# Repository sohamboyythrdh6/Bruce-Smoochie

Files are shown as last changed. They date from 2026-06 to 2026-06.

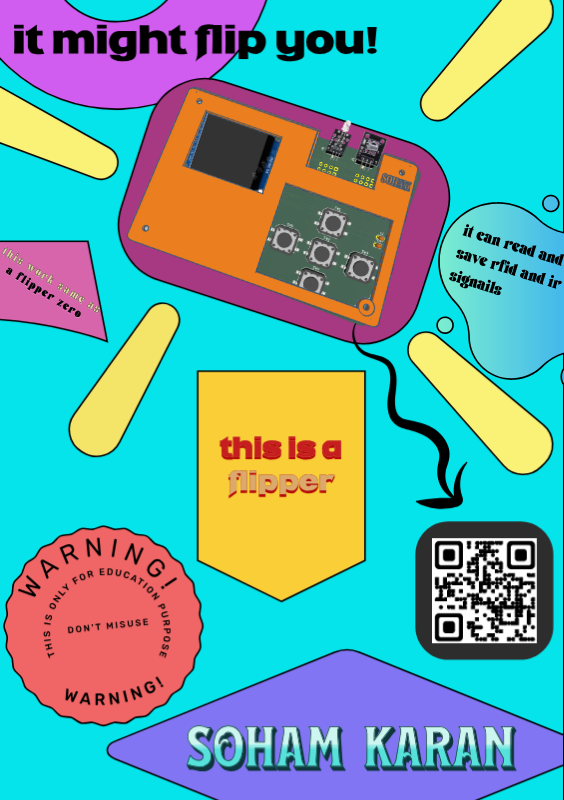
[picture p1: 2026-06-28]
zine.png

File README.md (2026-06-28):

# Bruce-Smoochie
zine

hey my name is soham karan and I am from India. i made a simmiler thing like flipper zero which can read rf tags and save it or use it later it also work same witr ir .And it just work as like flipper zero but it cheapper than flipper and you can also able to made by cheaking this repo .I made this project using esp s3 and some other components .ANd this project is powerd by a lipo battery which is charged by tp4506 charging module.
And to program the board you dont need any code insted you need a flash software which is given in my repo called firmware
and also insted of making a 3d printed case i just use the pcb to create a compact case. You just need to connect the two pcbs using Standoff Spacer Pillars.

                                             !warning! 

this project is just for education and learning purpose so please dont misuse this project.
   !!Bruce is a tool for cyber offensive and red team operations, distributed under the terms of the Affero General Public License (AGPL). It is intended for legal and authorized security testing purposes only. Use of this software for any malicious or unauthorized activities is strictly prohibited. By downloading, installing, or using Bruce, you agree to comply with all applicable laws and regulations. This software is provided free of charge, and we do not accept payments for copies or modifications. The developers of Bruce assume no liability for any misuse of the software. Use at your own risk.!!

  



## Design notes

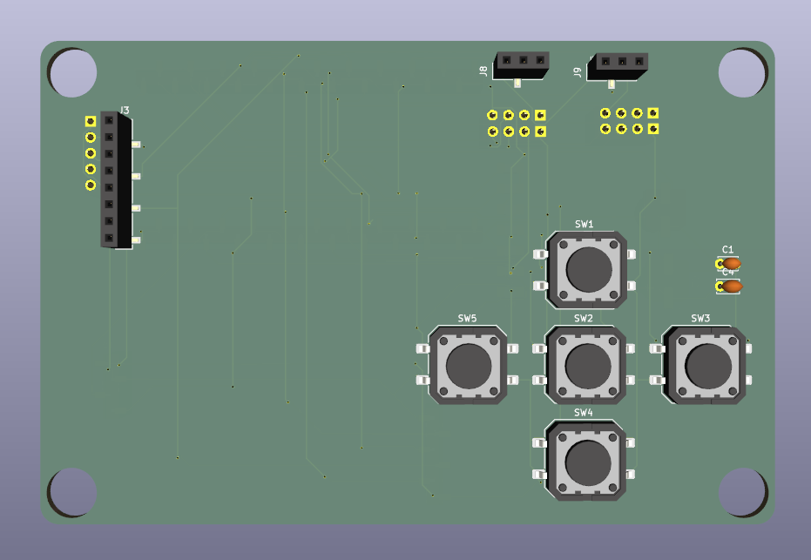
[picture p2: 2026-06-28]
Assets/Screenshot 2026-06-28 220822.png

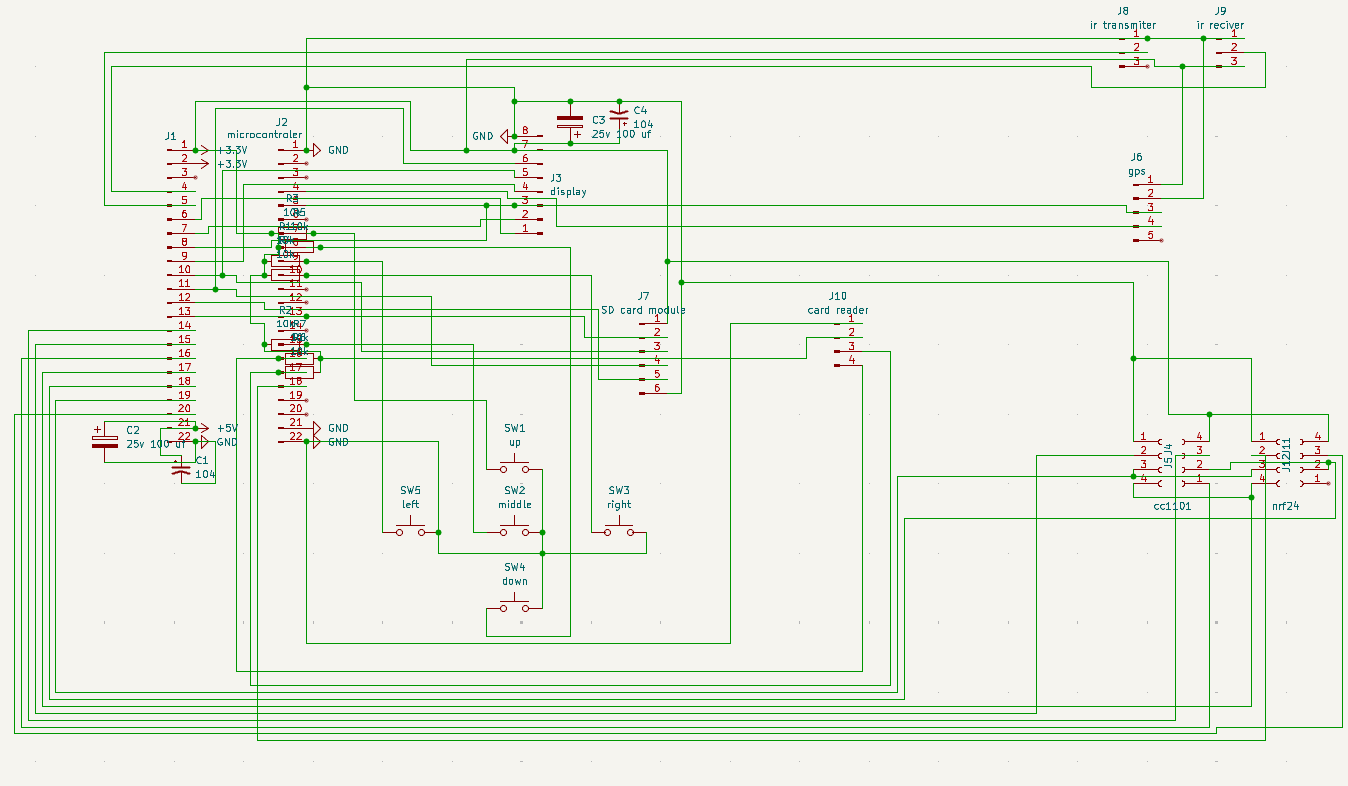
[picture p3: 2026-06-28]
Assets/Screenshot 2026-05-24 214158.png

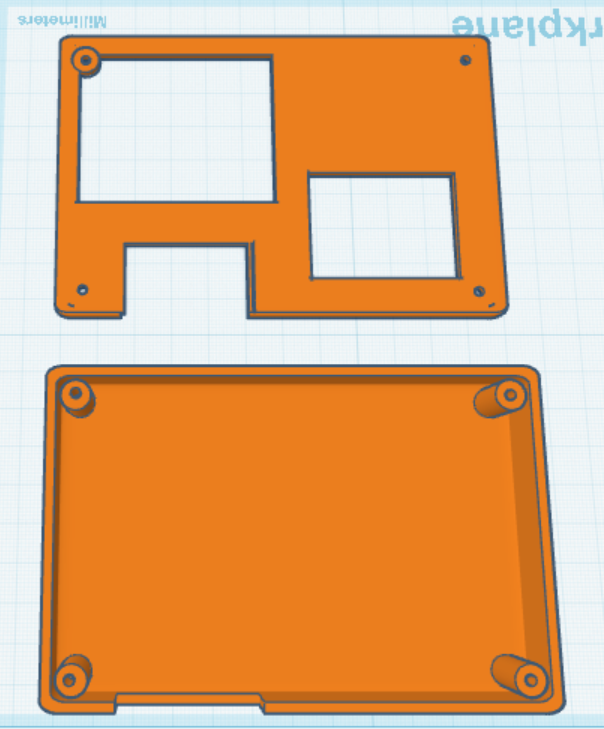
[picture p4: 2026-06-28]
Assets/Screenshot 2026-06-28 214658.png

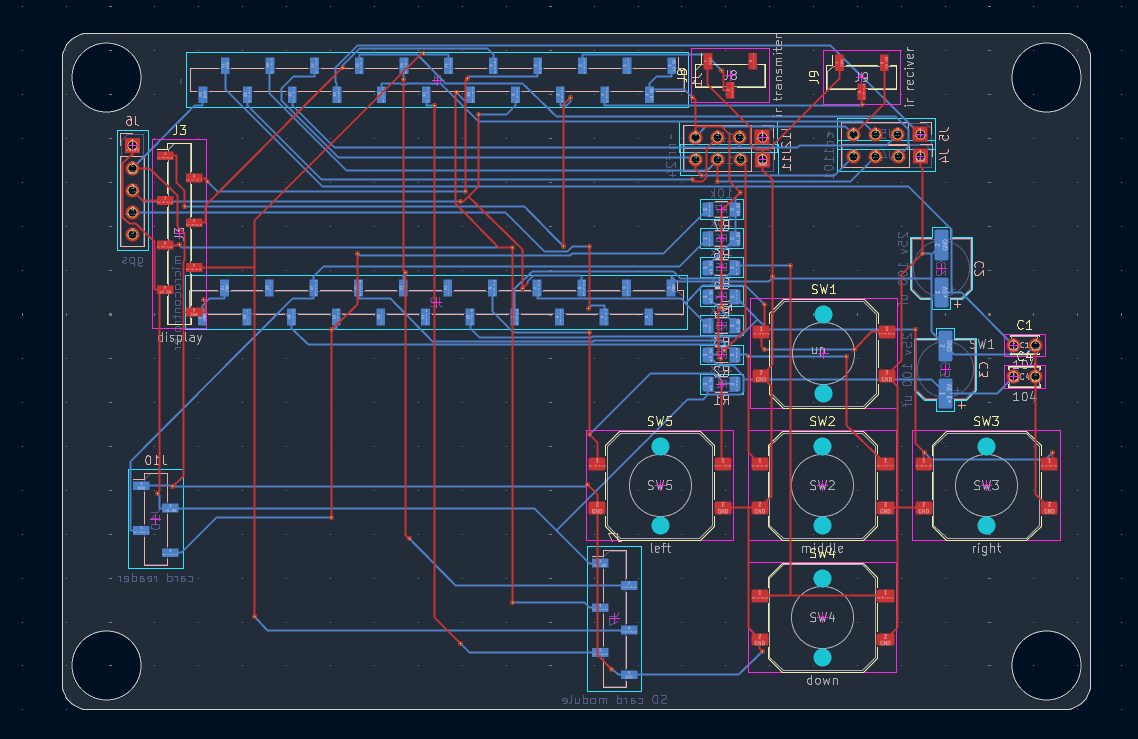
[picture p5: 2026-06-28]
Assets/Screenshot 2026-06-28 220758.png

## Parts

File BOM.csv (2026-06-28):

item | quantity | link | price(Dollar) | description
ESP32-S3 N16R8 | 1 | https://makerbazar.in/products/esp32-s3-wroom-1-development-board-copy?variant=48942521352432 | 10.44 | main controler of this project
1.3inch led tft display | 1 | https://robu.in/product/st7789-driver-spi-interface-display-module/ | 3.76 | for visual settings
Micro SD Card Reader Module | 1 | https://robu.in/product/mini-micro-sd-card-reader-module/ | 0.25 | for read save codes from sd card
8gb micro sd card | 1 | bought from local stors |  | for save codes
NEO GPS Module | 1 | https://makerbazar.in/products/neo-gps-module-neo-m8n-neo-7m-neo-6m?variant=48251052622064 | 2.91 | for trace live location
CC1101 RF Module | 1 | https://quartzcomponents.com/products/cc1101-sma-antenna-wireless-transceiver-module?variant=45714339725546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 | 3.54 | for read rf signals
NRF24L01 Module | 1 | https://makerbazar.in/products/2-4ghz-nrf24l01-pa-lna-sma-wireless-transceiver-antenna?variant=44824810324208 | 1.51 | for generate rf signals
PN532 NFC Module | 1 | https://robu.in/product/pn532-nfc-rfid-read-write-module-v3-kit/ | 2.97 | for read rfid cards
IR Receiver module | 1 | https://robu.in/product/infrared-receiver-module-arduino/ | 0.23 | for catch ir signals
IR Transmitter Sensor Module | 1 | https://robu.in/product/digital-38khz-infrared-transmitter-module/ | 0.41 | for transmit saved ir signails
4000mah lipo battery | 1 | https://robu.in/product/nova-105080-4000mah-3-7v-micro-lipo-battery-pack/ | 6.51 | for power the flipper
TP4056 Li-ion 18650 3.7V 4.2V Battery Charger Board DC-DC Step Up Boost Module | 1 | https://makerbazar.in/products/3-5v-to-5v-9v-lithium-battery-charge-discharge-adjustable-module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 | 0.51 | for charge the battery and stable the voltage
2.54mm 1x40 Pin Female Single Row SMT Header Strip | 2 | https://robu.in/product/2-54mm-1x40-pin-female-single-row-smt-header-strip-pack-of-5/ | 1.25 | for connect sensore and microcontrolers
2.54mm Pin male Single Row SMT Header | 2 | https://robu.in/product/1-month-warranty-628/ | 1 | for connect components
female pin header | 1 | https://robu.in/product/2-54mm-1x40-pin-female-single-row-header-strip-pack-of-10/ | 0.12 | for connect components
104 ceramic disk capasitor | 2 | https://makerbazar.in/products/ceramic-capacitor?variant=45523163185392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 | 0.20 | for insulating the circuit
button | 5 | https://robu.in/product/tact-switch-tk-012d-4pins-12x12-smd/ | 0.31 | for control the flipper
M4 X 20mm Male to Female Brass Hex Threaded Pillar Standoff Spacer | 4 | https://robu.in/product/m4-x-20mm-male-to-female-brass-hex-threaded-pillar-standoff-spacer-6-pcs/ | 1.66 | for connect pcb boards
4mm Stainless Steel Allen Socket Head Nut-Bolt | 4 | https://makerbazar.in/products/stainless-steel-allen-head-nut-bolt-washer-set?variant=44137335947504 | 0.68 | for connect pcbs
100 uf 25v smd capasitor | 2 | https://robu.in/product/uul1e101mnl1gs-nichicon-100uf-25v-116ma120hz-%c2%b120-smdd8xl10mm-aluminum-electrolytic-capacitors-smd-rohs/ | 1.11 | for capasiting
10k smd resistor | 7 | https://robu.in/product/yageo-10k-ohm-1-4w-1206-surface-mount-chip-resistor-pack-of-50/ | 0.048 | for limiting the current
custom pcb | 1 | https://cart.jlcpcb.com/shopcart/cart/ | 8 | for mount and connect all components
3d printed case | 1 | https://cart.jlcpcb.com/shopcart/cart/ | 4.84 | cover the circuit
deliveri charges | 4 | JLCPCB.ROBU.MAKERBAZAR.QUARTZ | 18
total |  |  | 71

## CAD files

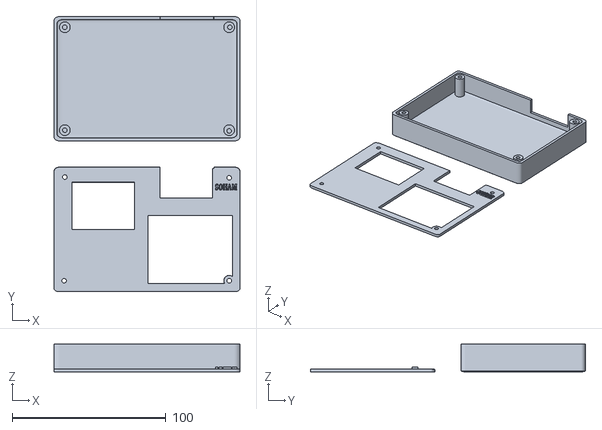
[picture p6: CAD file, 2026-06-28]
CAD/case.stl
121.0 x 179.0 x 18.0

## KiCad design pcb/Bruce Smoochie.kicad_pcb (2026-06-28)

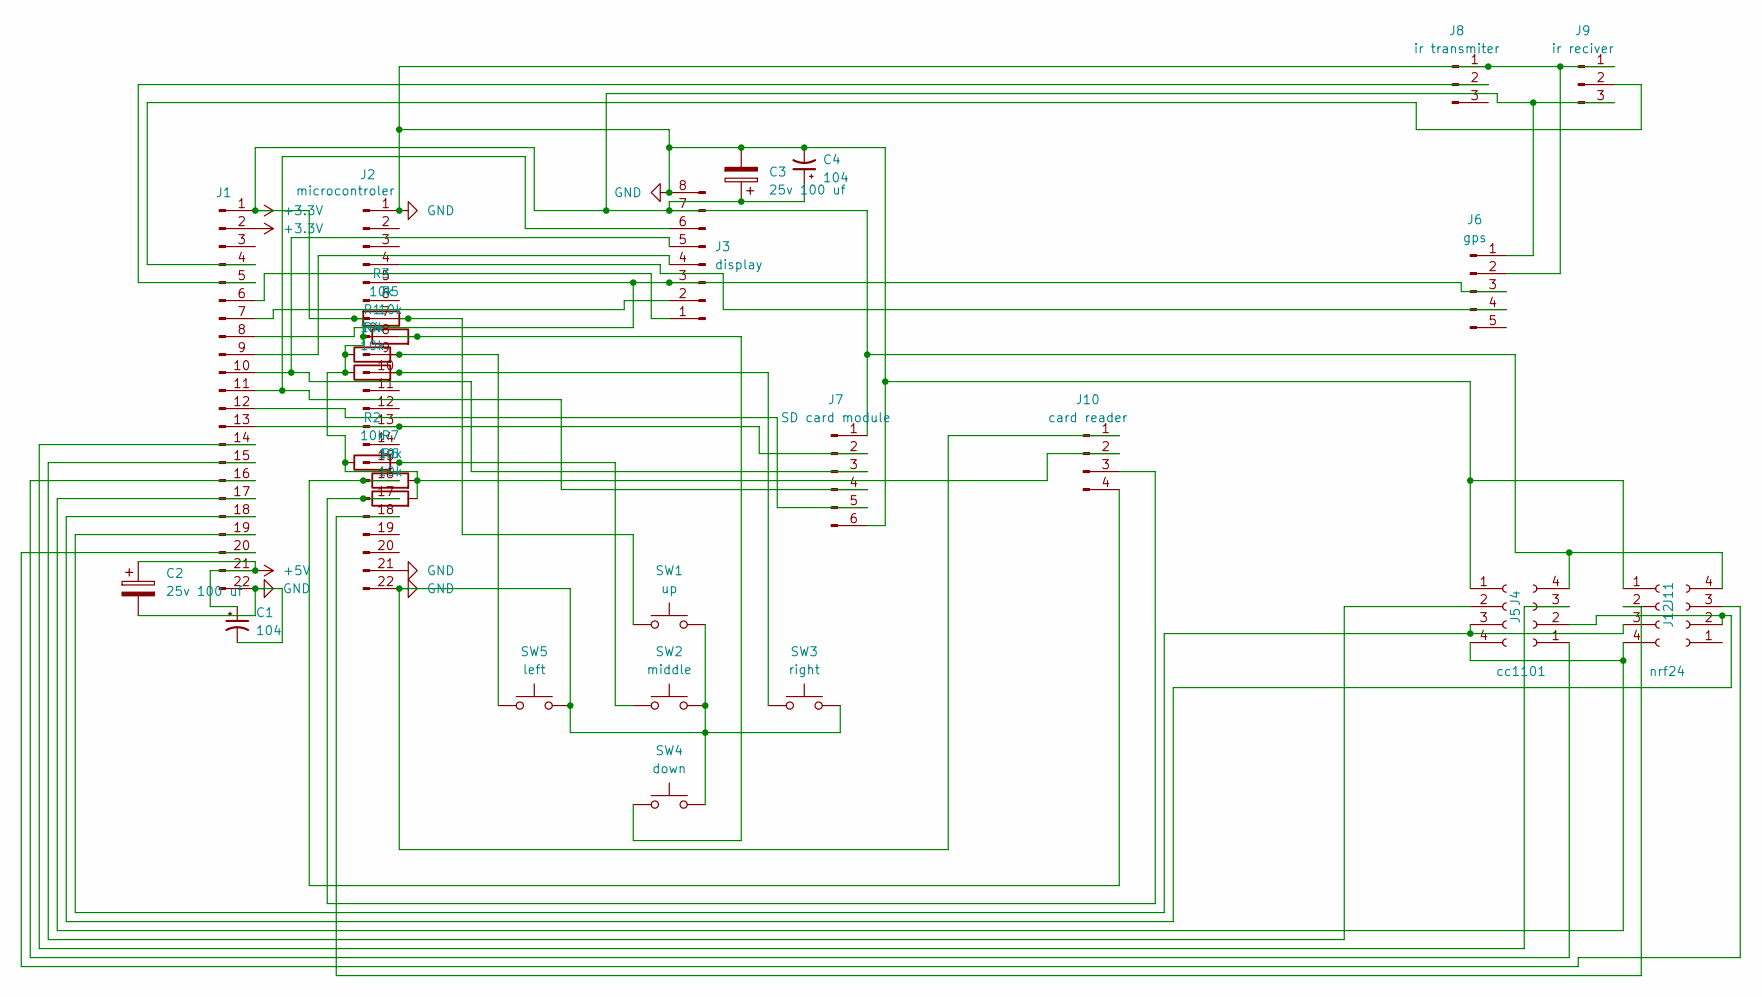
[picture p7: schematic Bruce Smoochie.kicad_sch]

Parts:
C1: 104; C_Disc_D3.0mm_W2.0mm_P2.50mm
C2, C3: 25v 100 uf; CP_Elec_6.3x7.7
C4: 104; C_Disc_D3.4mm_W2.1mm_P2.50mm
J1: PinSocket_1x22_P2.54mm_Vertical_SMD_Pin1Right
J2: microcontroler; PinSocket_1x22_P2.54mm_Vertical_SMD_Pin1Right
J3: display; PinSocket_1x08_P2.54mm_Vertical_SMD_Pin1Left
J4: cc1101; PinSocket_1x04_P2.54mm_Vertical
J5, J12: PinSocket_1x04_P2.54mm_Vertical
J6: gps; PinSocket_1x05_P2.54mm_Vertical
J7: SD card module; PinSocket_1x06_P2.54mm_Vertical_SMD_Pin1Right
J8: ir transmiter; PinSocket_1x03_P2.54mm_Vertical_SMD_Pin1Right
J9: ir reciver; PinSocket_1x03_P2.54mm_Vertical_SMD_Pin1Right
J10: card reader; PinSocket_1x04_P2.54mm_Vertical_SMD_Pin1Right
J11: nrf24; PinSocket_1x04_P2.54mm_Vertical
R1, R2, R3, R4, R5, R6, R7: 10k; R_1206_3216Metric_Pad1.30x1.75mm_HandSolder
SW1: up; SW_Push_1P1T_NO_CK_PTS125Sx43PSMTR
SW2: middle; SW_Push_1P1T_NO_CK_PTS125Sx43PSMTR
SW3: right; SW_Push_1P1T_NO_CK_PTS125Sx43PSMTR
SW4: down; SW_Push_1P1T_NO_CK_PTS125Sx43PSMTR
SW5: left; SW_Push_1P1T_NO_CK_PTS125Sx43PSMTR

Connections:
+3.3V: C3.1, C4.1, J1.1, J1.2, J3.7, J5.4, J6.1, J7.1, J9.3, J10.2, J12.4, R1.1, R2.1, R3.2, R4.1, R5.1, R6.2, R7.2
+5V: C1.1, C2.1, J1.21
GND: C1.2, C2.2, C3.2, C4.2, J1.22, J2.1, J2.21, J2.22, J3.8, J4.1, J6.2, J7.6, J8.1, J9.1, J10.1, J11.1, SW1.2, SW2.2, SW3.2, SW4.2, SW5.2
unnamed: J1.4, J9.2
unnamed: J1.5, J8.2
unnamed: J1.6, J3.1
unnamed: J1.7, J3.2
unnamed: J1.8, J2.5, J3.3, J6.3
unnamed: J1.9, J3.4
unnamed: J1.10, J3.5, J7.3
unnamed: J1.11, J3.6, J7.4
unnamed: J1.12, J7.5
unnamed: J1.13, J2.13, J7.2
unnamed: J1.14, J5.3
unnamed: J1.15, J4.2
unnamed: J1.16, J5.1
unnamed: J1.17, J4.4, J11.4
unnamed: J1.18, J5.2, J12.2
unnamed: J1.19, J4.3, J11.3
unnamed: J1.20, J12.3
unnamed: J2.4, J6.4
unnamed: J2.7, R3.1, SW1.1
unnamed: J2.8, R5.2, SW4.1
unnamed: J2.9, R1.2, SW5.1
unnamed: J2.10, R4.2, SW3.1
unnamed: J2.15, R2.2, SW2.1
unnamed: J2.17, J10.3, R6.1
unnamed: J2.16, J10.4, R7.1
unnamed: J2.18, J11.2

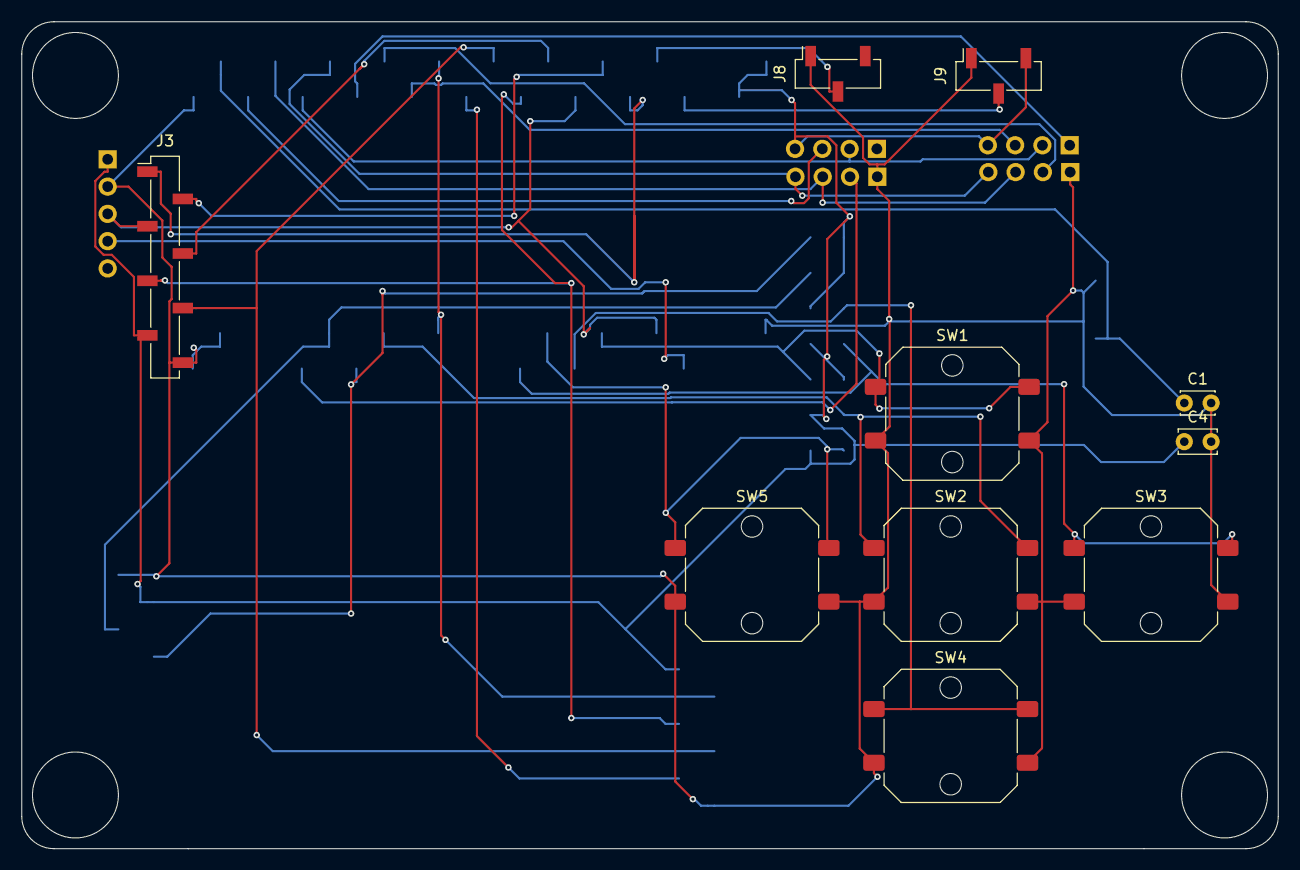
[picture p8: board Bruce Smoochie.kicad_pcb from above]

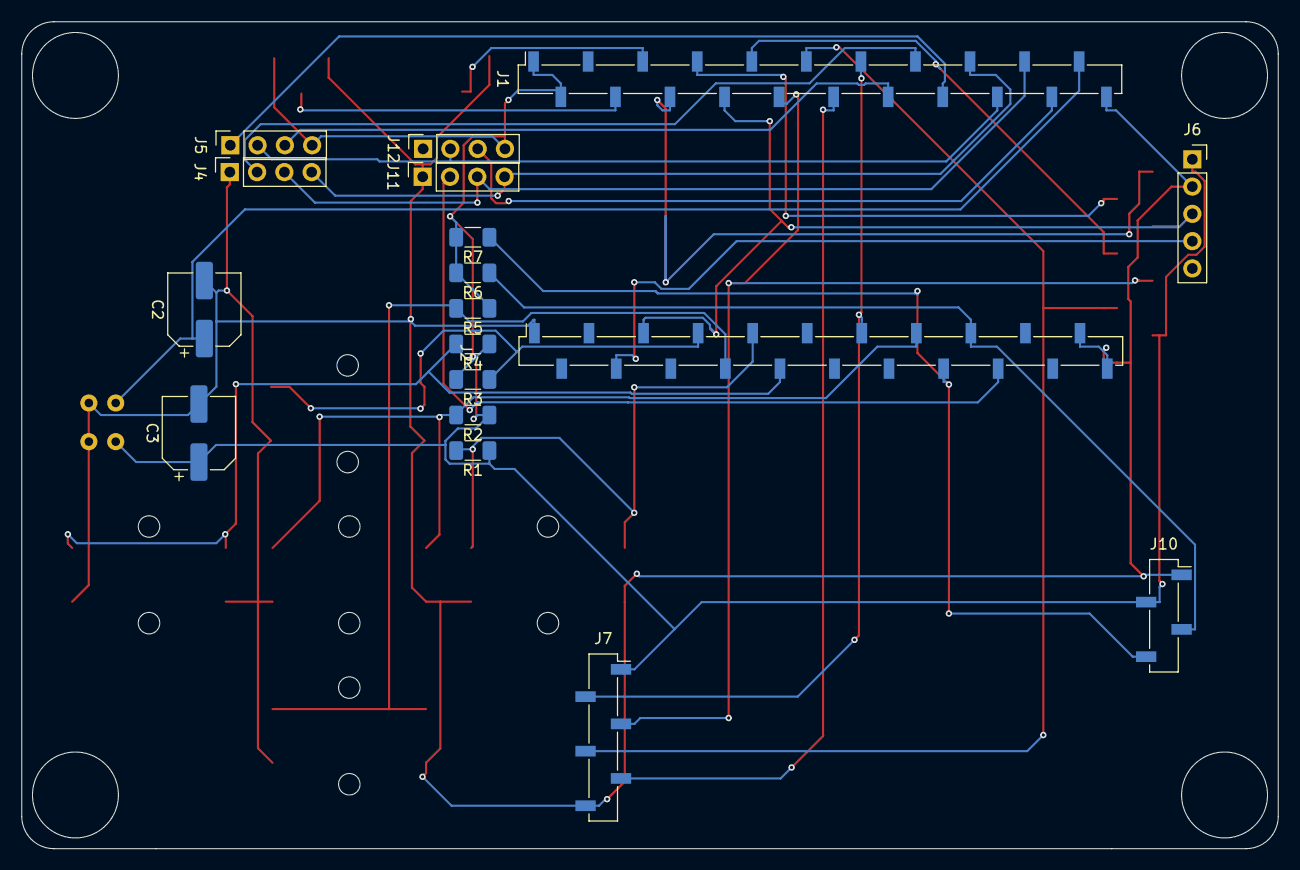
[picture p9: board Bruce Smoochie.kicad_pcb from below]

Board: 2 copper layers, 117.0 x 77.0 mm, 28 parts (18 on the bottom side), 29 nets.
